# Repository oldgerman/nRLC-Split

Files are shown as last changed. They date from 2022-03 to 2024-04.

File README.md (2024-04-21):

## nRLC-Split

[nRLC音频头版](https://oldgerman.github.io/1eb159fd/) 的制造文件（Manufacturing documentation for nRLC-Split）

### 关于

你第一次接触到本套文件可能是压缩包，内容可能滞后于仓库，制作前请访问[仓库地址](https://github.com/oldgerman/nRLC-Split)检查更新

PCB、原理图、钢网、外壳文件后续可能会改动，以最新的日期时间为准！

The first time you come into contact with this set of files, it may be a compressed package, and the content may lag behind the warehouse. Please visit the [github](https://github.com/oldgerman/nRLC-Split) to check for updates before making

PCB, schematic, stencil, and shell files may be changed later, the latest date and time shall prevail!

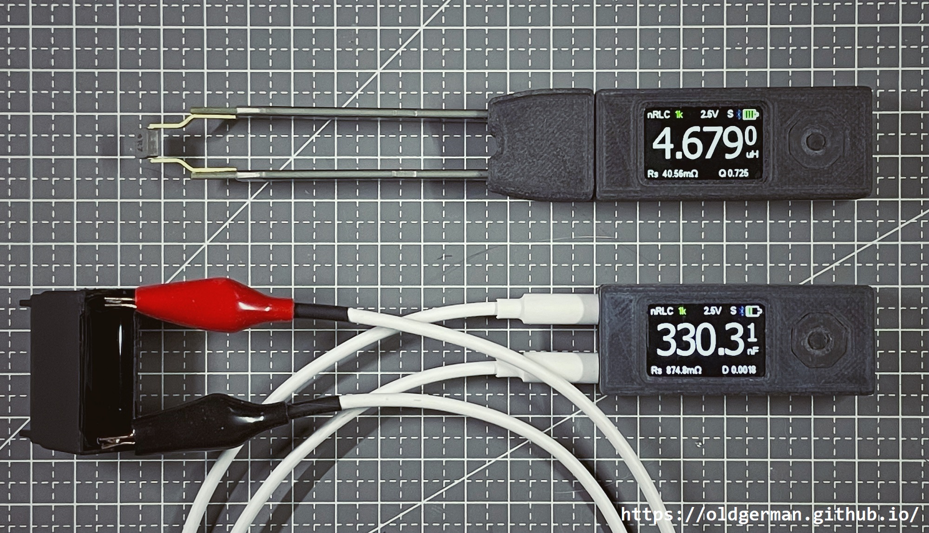
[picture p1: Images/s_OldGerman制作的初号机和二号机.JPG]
s_OldGerman制作的初号机和二号机


### 路径下各个文件夹的说明

```c
├─BOM                             // # PCB的物料清单，交互式BOM，使用浏览器打开
├─CAD                             // # 镊子触片CAD文件
├─Gerber                          // # 打板文件
│  ├─nRLC-Split                   // ## 【4层，板厚1.0mm】音频头版PCB
│  └─nRLC-Tweezers                // ## 【4层，板厚1.6mm】镊子PCB
├─Images                          // # 图片
├─Manual                          // # GFX网盘手册，添加了中文机器翻译
├─SCH                             // # 原理图
└─STL                             // # 3D打印模型
```

### 注意事项

PCB、原理图、钢网、外壳文件后续可能会改动，以最新的日期时间为准！

### 更新日志

| 日期 | 概述 | 制造文件变动 | 备注 |
| --- | --- | --- | --- |
| 2024-0504 之前 | 无 | 无 | 无 |
| 2024-0421 | 根据GFX网盘手册更新精确匹配的元件，在原理图中以粉色字体标出 | BOM、原理图  | 保留过去的BOM、原理图版本，但文件名添加了日期前缀 |

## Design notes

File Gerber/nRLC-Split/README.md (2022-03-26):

## PCB工艺 (PCB process)

PCB：4层板

厚：**1.0mm**

最小间隙：5mil

Gerber文件叠层顺序：GTL, G1, G2, GBL

PCB：4 layer 

Thickness：**1.0mm**

Minimum clearance：5mil

Gerber files stacking order: GTL, G1, G2, GBL

## 钢网 (SMT Stencil)

可以使用本路径下的 SMT_Stencil.GBP 文件给厂家制作10x10cm钢网，上下两张板的正反面都拼在这个文件内

You can use the SMT_Stencil.GBP file in this path to make a 10x10cm steel mesh for the manufacturer, and the front and back sides of the upper and lower boards are assembled in this file

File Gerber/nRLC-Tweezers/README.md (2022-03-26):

## PCB工艺 (PCB process)

PCB：4层板

厚：**1.6mm**

Gerber文件叠层顺序：GTL, G1, G2, GBL

PCB：4 layer 

Thickness：**1.6mm**

Gerber files stacking order: GTL, G1, G2, GBL

## 2021/03/24 文件修改 (Modify the files)

请使用PCB-Tweezers_0324_ZT.zip文件，修改部分：将3.5音频连接器悬空的第4引脚进行接地

这个修改不是致命缺陷，之前打过PCB-Tweezers_0301_ZT.zip文件的朋友不会产生本质的问题，具体区别如下：

- PCB-Tweezers_0301_ZT.zip文件：两条测试信号线在3.5音频连接器内部被第3脚包地

- PCB-Tweezers_0324_ZT.zip文件：两条测试信号线在3.5音频连接器内部被第3脚和第4脚包了两次地

Please use the PCB-Tweezers_0324_ZT.zip file, modified part: connect the 4th pin of the 3.5 audio connector to ground.

This modification is not a fatal flaw. Friends who have previously typed the PCB-Tweezers_0301_ZT.zip file will not have essential problems. The specific differences are as follows:

- PCB-Tweezers_0301_ZT.zip file: The two test signal lines are grounded by pin 3 inside the 3.5 audio connector.

- PCB-Tweezers_0324_ZT.zip file: The two test signal lines are grounded twice by pins 3 and 4 inside the 3.5 audio connector.

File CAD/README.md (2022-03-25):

## 镊子接触头CAD文件

文件`Tweezers_tips.DWG`和`Tweezers_tips.DXF`用软件导入查看时，单位请选mm

注意：激光切割只切外轮廓，不要切割两条折弯线

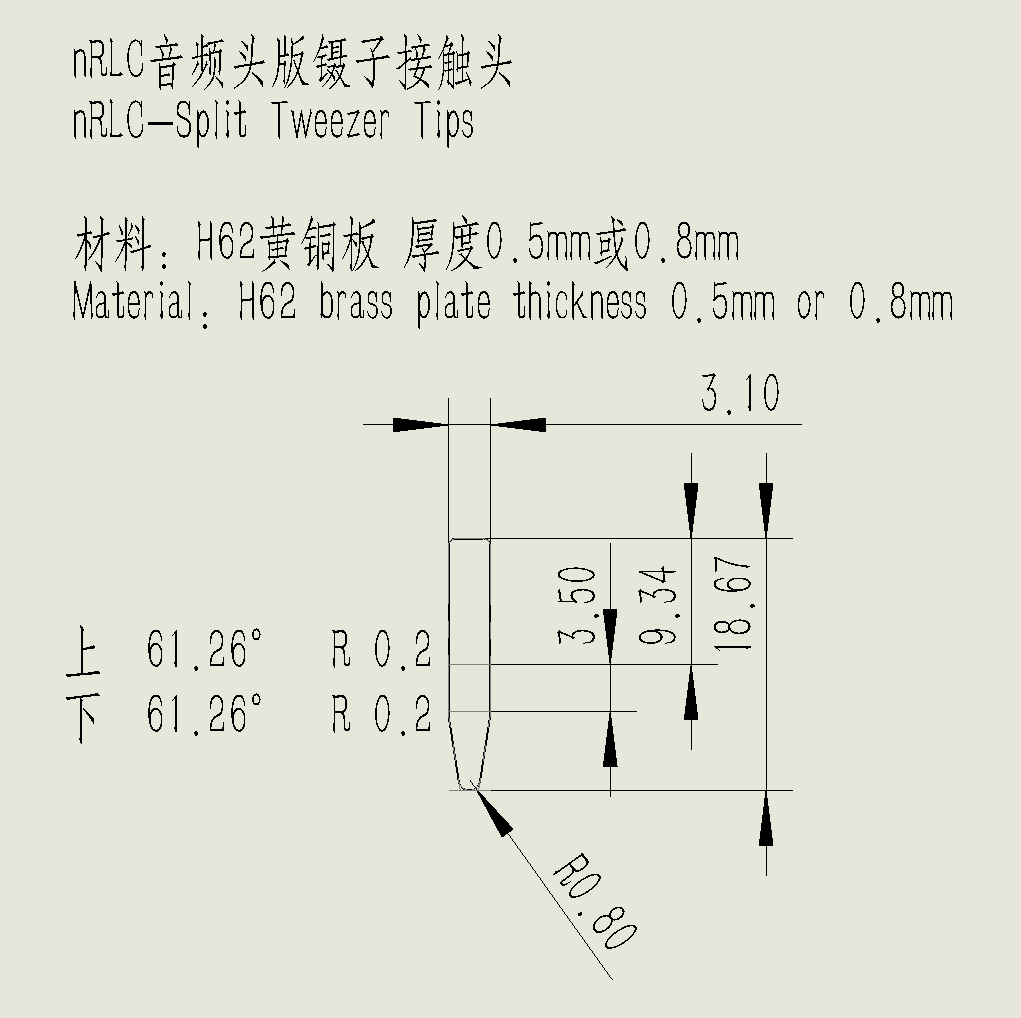
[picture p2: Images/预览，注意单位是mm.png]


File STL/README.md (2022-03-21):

## 外壳打印文件

###  一套外壳固定用的五金件

不锈钢内六角螺丝杯头 x5
	规格：M1.6x12 (螺纹/螺纹的长度)，[链接](https://item.taobao.com/item.htm?id=40272016203)

注塑热熔铜滚花螺母 x5
	规格：外2.5 M1.6 1.5高，[链接](https://item.taobao.com/item.htm?id=39063858665)

### 中心按钮

打印的中心按钮尺寸不一定精确，中心按钮装入周围按钮后，底部最好和周围按钮一样平，按下按键才不会误触，不平的话请用3mm圆锉刀修整侧壁

### 整机收纳壳

中心按钮预留高度较高，装入整机收纳壳需要打磨一定厚度

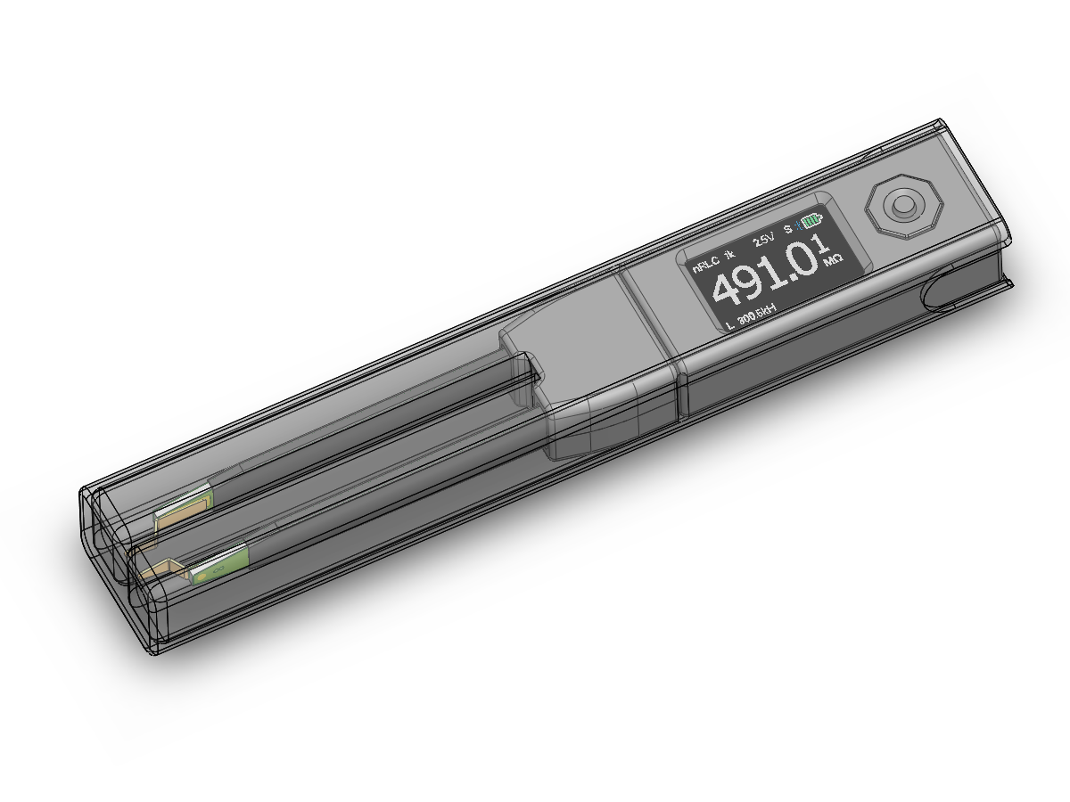
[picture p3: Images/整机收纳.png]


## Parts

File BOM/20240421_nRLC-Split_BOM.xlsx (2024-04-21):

Comment | Description | Designator | Footprint | LibRef | Quantity
Lipo_Battery_402030_180mAh |  | [NoValue], *1 | 402030锂电池180mAh(28x20x4mm) | Lipo_Battery | 2
ODG_LOGO |  | [NoValue], *2, *3, *4, *5, *6, *7, *8 | ODG_LOGO | ODG_LOGO | 8
BAT |  | BAT1 |  | BAT | 1
1uF | Capacitor | C1, C3, C5, C9, C10, C11, C13, C15, C16, C17, C19, C20, C23, C24, C26, C29, C31, C32, C33, C35, C36, C39, C41, C43, C48, C61, C63, C65, C67, C71, C73 | C0603 | CAP | 31
10uF | Capacitor | C2, C25, C38, C40, C42, C45, C47, C49, C53, C54, C55, C56, C59, C66, C68, C72 | C0603 | CAP | 16
47uF/6.3V | Capacitor | C4, C8, C12, C14, C21, C30, C37 | CAP_POL_3216 | CAP_Polar | 7
100pF | Capacitor | C6, C7 | C0603 | CAP | 2
100pF/1% | Capacitor | C18, C22, C27, C34 | C0603 | CAP | 4
N/I | Capacitor | C28, C46, C50, C52 | C0603 | CAP | 4
0.1uF | Capacitor | C44, C51, C60, C62, C64, C69, C70 | C0603 | CAP | 7
10pF | Capacitor | C57, C58 | C0603 | CAP | 2
1nF | Capacitor | C74 | C0603 | CAP | 1
SRV05-4MR6T1G | 钳位IC | D1 | MICROCHIP SOT-23-6 M6 | SRV05-4 | 1
USBLC6-2 | Very low capacitance ESD protection Features • 2 data-line protection • Protects VBUS • Very low capacitance: 3.5 pF max. • Very low leakage current: 150 nA max. • SOT-666 and SOT23-6L packages • RoHS compliant | D2 | MICROCHIP SOT-23-6 M6 | USBLC6-2 | 1
1N4148WT |  | D3 | SOD-523 | DIODE | 1
AD8605ARTZ | 精密、低噪声、CMOS、轨到轨输入/输出运算放大器 | DA1, DA5 | ANALOG SOT-23-5 RJ-5 | AD8605ARTZ | 2
AD8542ARMZ或AD8542ARUZ | 通用型CMOS双路轨到轨放大器 General-Purpose CMOS Dual Rail-to-Rail Amplifier | DA2 | TSSOP-8+MSOP-8 | AD8542 | 1
INA826AIDGKR或INA826SIDRCR | 具有轨至轨输出和关断的 INA826S 精密 200µA 电源电流，3V 至 36V 电源 仪表放大器 | DA4, DA6 | MSOP-8+PVSON-10 | INA826S | 2
10uH |  | L1, L2, L3, L4, L5, L6, L7, L10, L11, L12 | L0603 | FUSE | 10
10uH_0805 |  | L8 | L0805 | FUSE | 1
2.2uH |  | L9 | TAIYO YUDEN MAMK2520T1R0M | Inductor | 1
LED | LED | LED1 | LED 0603_1608 | LED | 1
12mm 陶瓷蜂鸣片 | Speaker | LS1 | 压电陶瓷蜂鸣片12MM | Speaker | 1
PJ320 |  | P1, P2, P11, P12 | PJ320A | PJ320 | 4
1.27mm_10P_母座 | 1.27mm 母座 10pins | P3, P4 | 1.27mm_Female_x10 | DS1065-01-1X10S8BV | 2
1.27mm_10P_排针 | 1.27mm 排针 10pins | P5, P6 | 1.27mm_male_x10 | ZL319-10P | 2
1.27mm_2P_母座 |  | P7, P8 | 1.27mm_Female_x2 | CONN_2P | 2
1.27mm_2P_排针 |  | P9, P10 | 1.27mm_male_x2 | CONN_2P | 2
P-MOS | P-MOS | Q1, Q3 | INFINEON SOT-23-3 | P-MOS | 2
N-MOS | N-MOS | Q2, Q4 | INFINEON SOT-23-3 | N-MOS | 2
15K | Resistor | R1, R8 | R0603 | RES | 2
1K | Resistor | R2, R13, R21, R22, R26, R37, R61 | R0603 | RES | 7
5.1K | Resistor | R3, R57, R58 | R0603 | RES | 3
10R | Resistor | R4, R11, R14, R20, R60 | R0603 | RES | 5
100K | Resistor | R5, R6, R36, R38, R41, R51, R52 | R0603 | RES | 7
10K | Resistor | R7, R34, R39, R40, R43, R44, R48 | R0603 | RES | 7
100R | Resistor | R9, R23, R33, R54 | R0603 | RES | 4
22R | Resistor | R10, R15, R25, R29 | R0603 | RES | 4
30K | Resistor | R12 | R0603 | RES | 1
1M/0.1% | Resistor | R16, R31 | R0603 | RES | 2
2K/0.1% | Resistor | R17, R18, R24, R32 | R0603 | RES | 4
1M | Resistor | R19, R28 | R0603 | RES | 2
100R/0.1% | Resistor | R27 | R0603 | RES | 1
10K/0.1% | Resistor | R30 | R0603 | RES | 1
40.2K | Resistor | R35 | R0603 | RES | 1
N/I | Resistor | R42, R45, R46 | R0603 | RES | 3
47K | Resistor | R47, R53, R55, R59 | R0603 | RES | 4
2M | Resistor | R49 | R0603 | RES | 1
205K | Resistor | R50 | R0603 | RES | 1
1.5K | Resistor | R56 | R0603 | RES | 1
RES-8P4R-100R | 贴片网络排阻 | RN1 | RESNET 1206-8 CONCAVE | RES-8P4R | 1
RES-8P4R_100R | 贴片网络排阻 | RN2, RN4 | RESNET 1206-8 CONCAVE | RES-8P4R | 2
RES-8P4R_22R | 贴片网络排阻 | RN3 | RESNET 1206-8 CONCAVE | RES-8P4R | 1
KLS7-MT-08 | KLS五向开关10*10*1.5mm 兼容松下EVQQ3KA15 TT5 | SW1 | KLS7-MT-08 | KLS7-MT-08 | 1
PGA113AIDGST |  | U1, U2 | TI MSOP-10 DGS | PGA113 | 2
SN74LVC1G3157DCKR | 5V、2:1 (SPDT)、单通道通用模拟开关 5-V, 2:1 (SPDT), 1-channel general-purpose analog switch | U3, U4 | DIODES SOT-363 | SN74LVC1G3157DCKR | 2
MCP73831T或LTC4054或TP4054 |  | U5 | MICROCHIP SOT-23-5 OT | MCP73831T | 1
MCP1700T-3302E/TT | 低压差线性稳压芯片 | U6 | MICROCHIP SOT-23-3 NB | MCP1700T-3302E/TT | 1
ADP150AUJZ-3.3-R7或LDK 120M33R或LP5907MFX | 超低噪声线性稳压芯片 | U7 | ANALOG TSOT-23-5 UJ-5 | ADP150AUJZ-3.3-R7 | 1
STM32F303CCT6或STM32F303CBT6 | 带DSP和FPU的主流混合信号ARM Cortex-M4 MCU，具有128 KB Flash、72 MHz CPU、MPU、CCM、5 MSPS 12位ADC、PGA和比较器 | U8 | ST LQFP-48 7x7MM | STM32F303CBT6 | 1
CCR2640R2F | CC2640R2F 无线蓝牙串口模块 | U9 | 信驰达_RF-BM-4044B5 | 信驰达_RF-BM-4044B5 | 1
SPX3819M5-L-5-0/TR或TPS76350DBVR或SPX5205M5-L-5-0/TR | 超低噪声线性稳压芯片 | U10 | ANALOG TSOT-23-5 UJ-5 | ADP150AUJZ-3.3-R7 | 1
TPS63000 | Buck-Boost Converter 具有 1.8A 电流开关并采用 3x3 QFN 封装的高效率降压/升压转换器 | U11 | TI PVSON-10 3x3MM DRC | TPS63000 | 1
74HC1G32GV.125或SN74AHC1G32DBVR | IC GATE OR | U12 | TI SOT-23-5 DBV | SN74AHC1G32DBVR | 1
IPS-LCD-1.14inch | IPS-LCD-1.14寸裸屏spi接口 | U13 | TFT_1.14IN_240X135_WRAPUNDER | IPS-LCD-1.14inch | 1
BMI160 | IMU combining accelerometer and gyroscope. Package dimensions 2.5x3.0x0.8mm³ The small, low power BMI160 is a low noise 16-bit IMU designed for mobile applications such as AR or indoor navigation, providing highly accurate sensor data and real-time sensor data. The low current consumption of BMI160 enables always-on applications in battery-driven devices. This sensor features a configurable on-chip interrupt engine which provides motion-based gesture recognition and context awareness as always-on background functions. The BMI160 is compatible with the Qeexo FingerSense application. | U14 | BOSCH LGA-14 2.5x3 - large | BMI160 | 1
CCR2640R2F | CC2640R2F 无线蓝牙串口模块 | U15 | 信驰达_RF-BM-4044B4 | 信驰达_RF-BM-4044B5 | 1
Type-C_16P插脚（需要按照教程魔改） |  | USB1 | Type-C-TOP-前插后贴 | USB-Type-C-24P | 1
BAV99W | Dual Series Switching Diodes | VD1 | DIODES SOT-323-3 | BAV99W | 1
BAT54CW | 贴片肖特基二极管 | VD2, VD3 | DIODES SOT-323-3 | BAT54CW | 2
12MHz/10pF | 4脚无源晶振 | X1 | EPSON TSX-3225 | XTAL-4P | 1

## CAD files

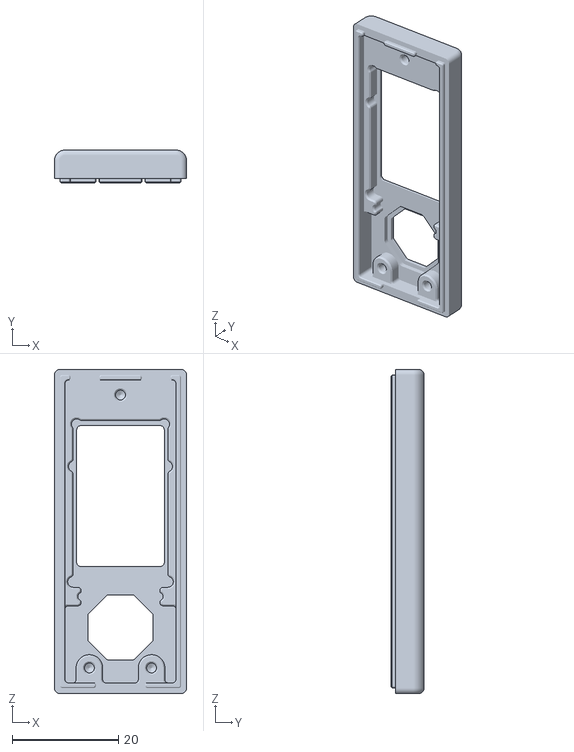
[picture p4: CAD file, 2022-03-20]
STL/主体外壳_上壳(main_body_shell_top).STL
24.8 x 6.20 x 60.9

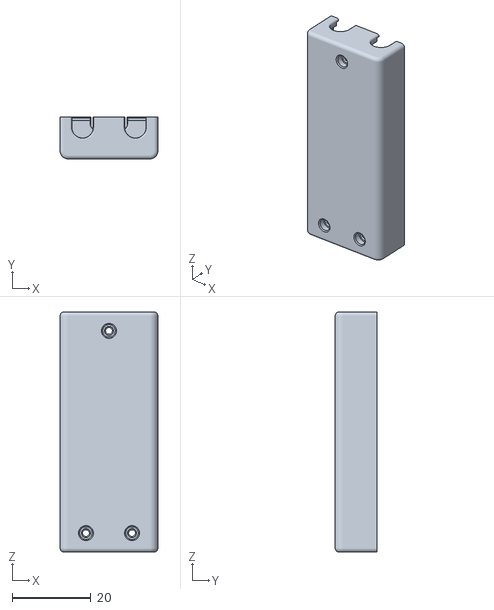
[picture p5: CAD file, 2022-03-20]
STL/主体外壳_下壳(main_body_shell_bottom).STL
24.8 x 10.6 x 60.9

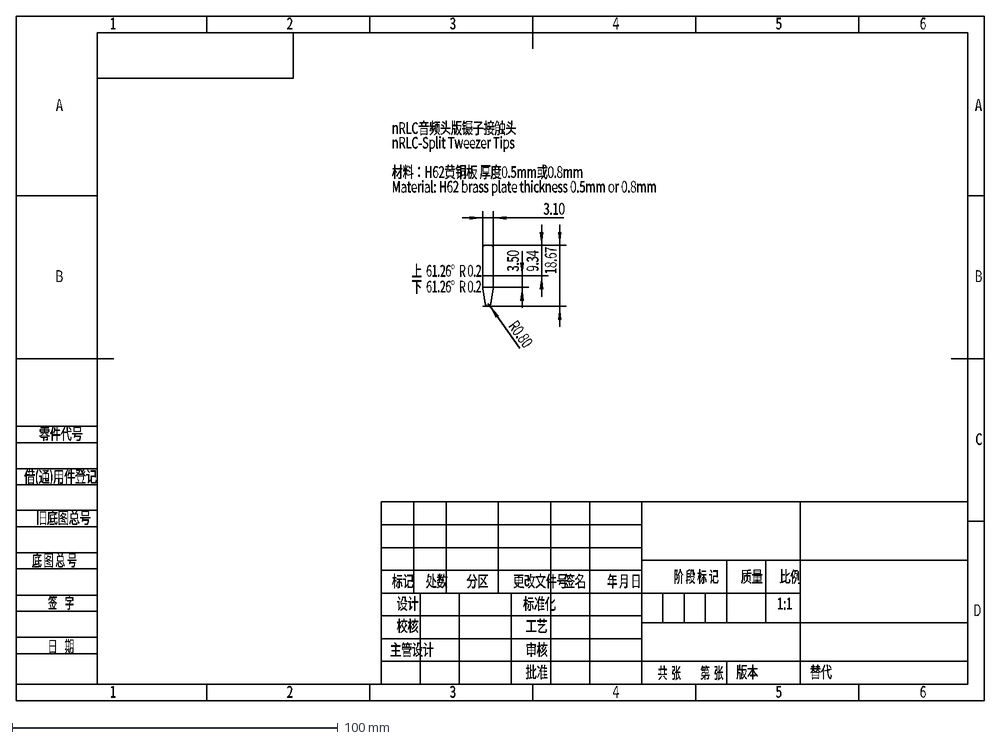
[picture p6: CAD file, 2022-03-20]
CAD/Tweezers_tips.DXF
nRLC音频头版镊子接触头
nRLC-Split Tweezer Tips
材料：H62黄铜板 厚度0.5mm或0.8mm
Material: H62 brass plate thickness 0.5mm or 0.8mm
替代
版本
审核
工艺
比例
质量
第 张
共 张
阶 段 标 记
批准
标准化
主管设计
年 月 日
签名
更改文件号
分区
处数
标记
设计
校核
零件代号
借(通)用件登记
旧底图总号
底 图 总 号
日 期
1:1
1
B
A
D
C
签 字
2
5
4
3
6
3.10
18.67
R0.80
9.34
3.50
上 61.26° R 0.2
下 61.26° R 0.2

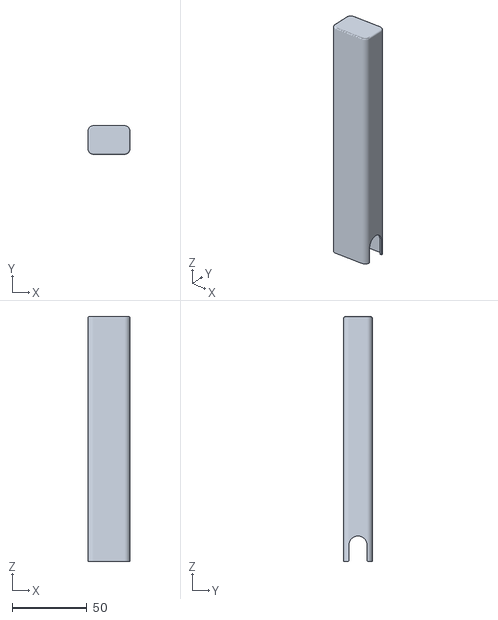
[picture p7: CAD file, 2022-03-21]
STL/整机收纳壳(machine storage case).STL
28.0 x 19.2 x 163.7

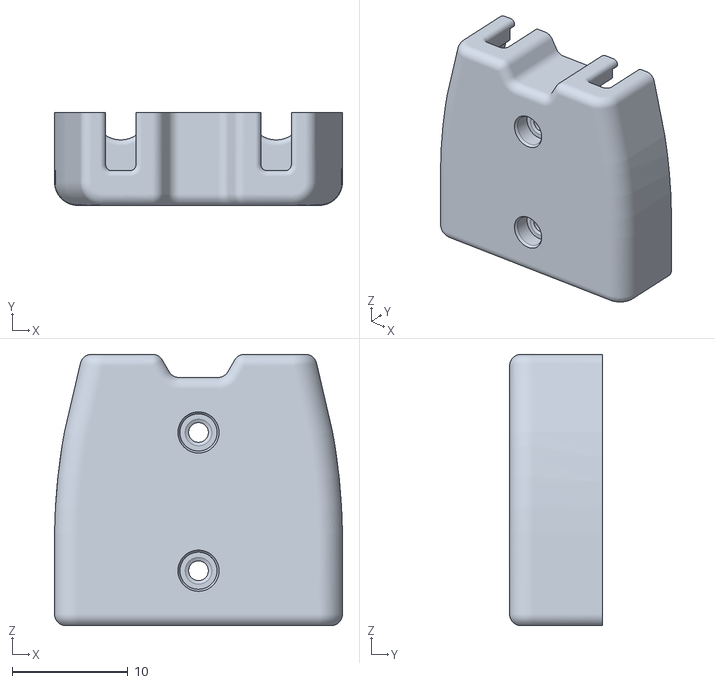
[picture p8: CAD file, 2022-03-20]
STL/镊子外壳-下壳(tweezers_case_bottom).STL
24.8 x 8.00 x 23.4

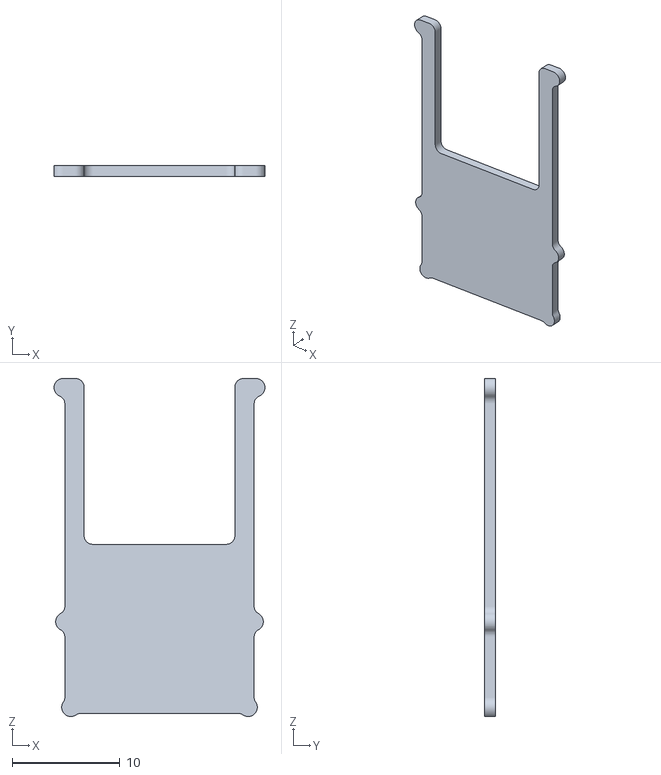
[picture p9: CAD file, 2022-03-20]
STL/屏幕垫片(display_gasket).STL
19.6 x 1.00 x 31.3

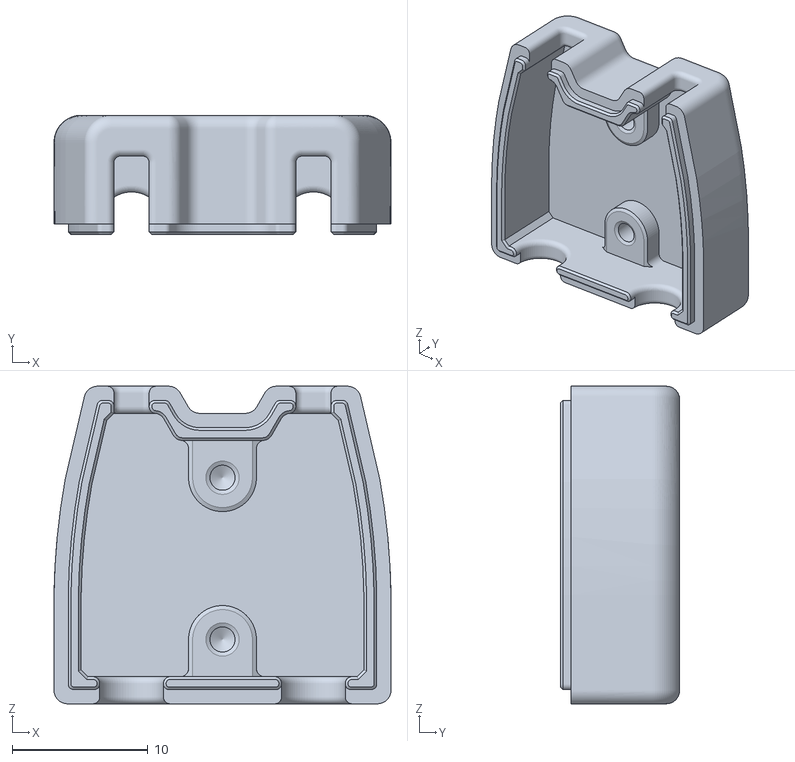
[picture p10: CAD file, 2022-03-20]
STL/镊子外壳-上壳(tweezers_case_top).STL
24.8 x 8.80 x 23.4

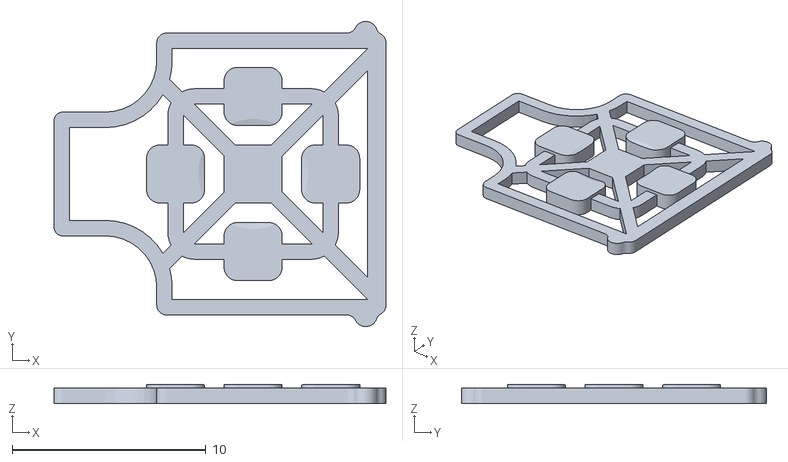
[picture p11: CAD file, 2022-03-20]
STL/按钮垫片(button_gasket)_0.8mm.STL
17.1 x 15.7 x 1.00

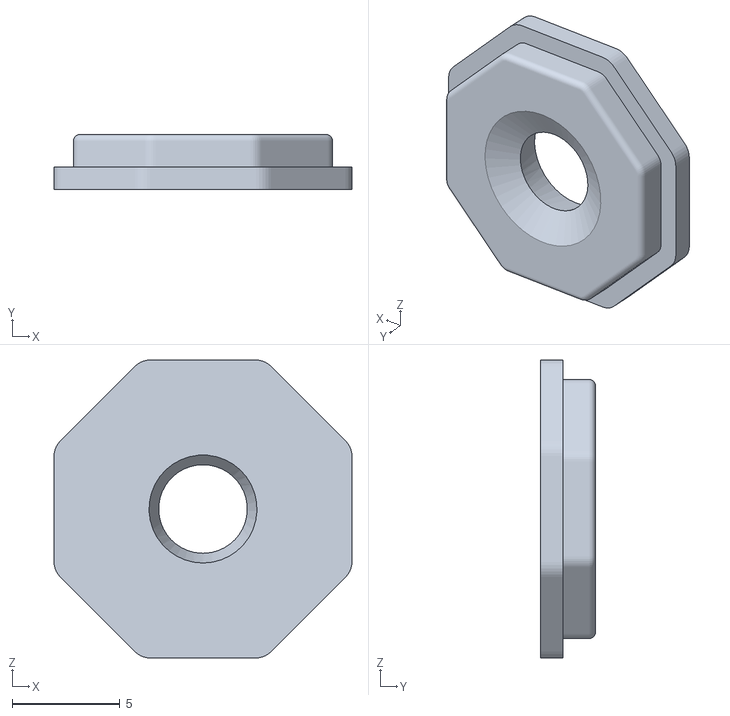
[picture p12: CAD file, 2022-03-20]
STL/周围按钮(surround_button).STL
13.8 x 2.55 x 13.8

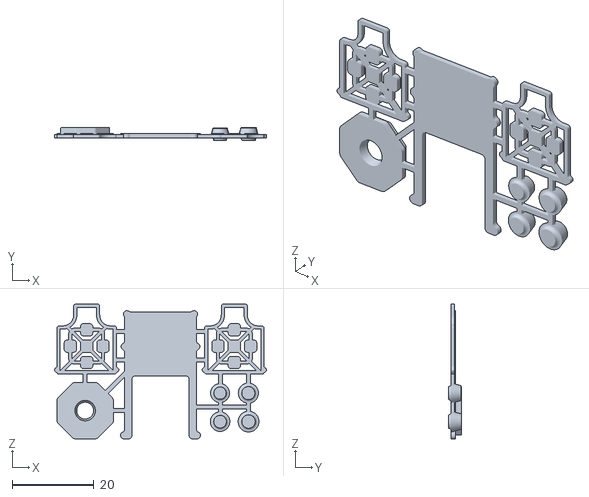
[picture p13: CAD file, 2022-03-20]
STL/链接零件(link_parts).STL
51.8 x 3.26 x 32.9

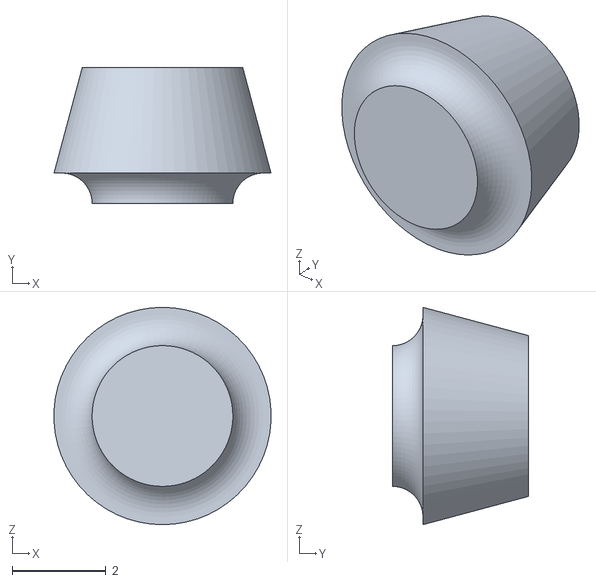
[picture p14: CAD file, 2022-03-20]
STL/中心按钮(center_button).STL
4.63 x 2.90 x 4.63

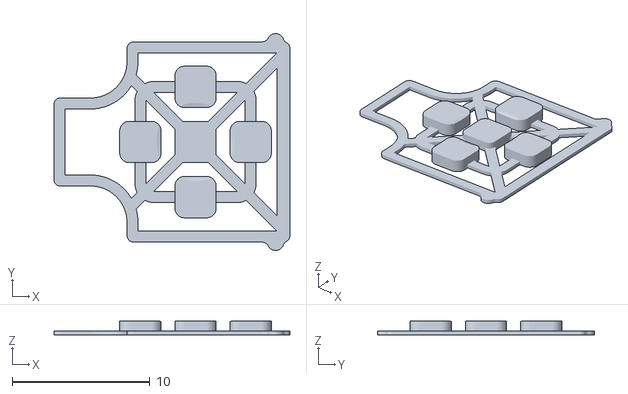
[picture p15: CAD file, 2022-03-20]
STL/按钮垫片(button_gasket)_0.3mm.STL
17.1 x 15.7 x 1.00

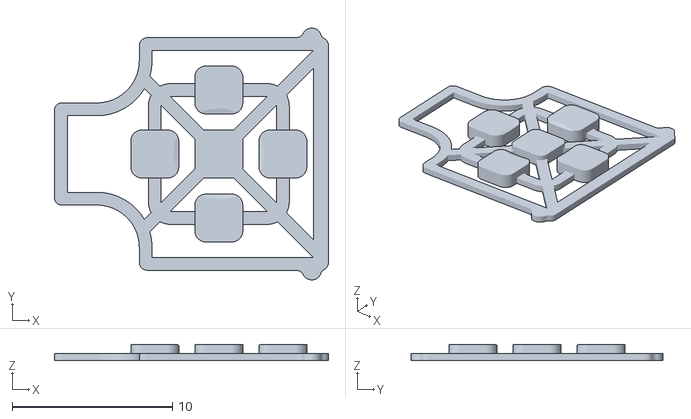
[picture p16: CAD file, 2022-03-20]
STL/按钮垫片(button_gasket)_0.45mm.STL
17.1 x 15.7 x 1.00

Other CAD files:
CAD/Tweezers_tips.DWG

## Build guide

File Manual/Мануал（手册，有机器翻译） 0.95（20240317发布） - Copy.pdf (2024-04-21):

Особенности схемотехники, подбор элементов.

ОУ недопустимо покупать у непрверенных поставщиков в т.ч у китайцев. В условиях дефицита (02.2022) на INA826 контрафактнеМС могут реализовываться и уважаемыми магазинами. МК брать у китайцев нежелательно, хотя и есть положительные отзывы по работоспособности. На качество работы прибора напрямую влияют встроенные АЦП которые в китайских МК могут быть низкого качества.
В схеме имеются элементы, которые должны быть прецизионные, либо специально подобранные. Качество подбора напрямую влияет на точность измерения.
К таким элементам относятся:
- Токовые шунты R1, R2 должны быть прецизионные резисторы с точностью 0,1%. Должны строго подбираться пары элементов в каналах напряжения и тока , абсолютный номинал не столько критичен, важно абсолютное равенство значений в паре. Отклонение в значениях в паре приведет к повышению погрешностей. Необязательно брать 0,1% резисторі, можно взять в избытке 1-5% и отсортировать равные.
R13= R15
R18=R20
R26=R27
C16=C18
Конденсаторы влияют тем больше, чем выше рабочая частота, низкокачественніе дополнительно вносят искажения в сигнал и снижают точность, должны устанавливаться обязательно NP0, подобранные в пары:
С16=С18,
С24=С25.
Данные конденсаторы можно не устанавливать до полного монтажа и настройки прибора, а отсортировать самим же прибором и установить после полного запуска.

Первичная оценка работоспособности. Проведение доработок. Собранный из качественных и подобранных элементов прибор в настройке не нуждается. Даже без калибровок должен измерять с погрешностью не хуже 0.5% в центре диапазона 100 Ом- 100К. Если это не так, следует искать причину, прежде всего в аналоговой части. Не пытайтесь калибровать прибор с кривоработающей аналоговой частью, необходимо найти и устранить причину,
Для поиска неисправностей имеются ряд встроенных инструментов:
- Инженерный экран
- Осцилографический экран
- Отключение ДАК в меню- позволяет отключить тестовый сигнал и убедиться в том, что в каждой контрольной точке имеется допустимое значение REF, отсутствует генерация/ возбуд и т.д

- Ручная установка РУИ, позволяет в ручном режиме проверить масштабируемость КУ программируемого усилителя, работу каждого шунта в отдельности и т .д

### Второй экран

(инженерный), переключается нажатием кнопки «Влево». Отображает всю доступную информацию измерения и расчетов.

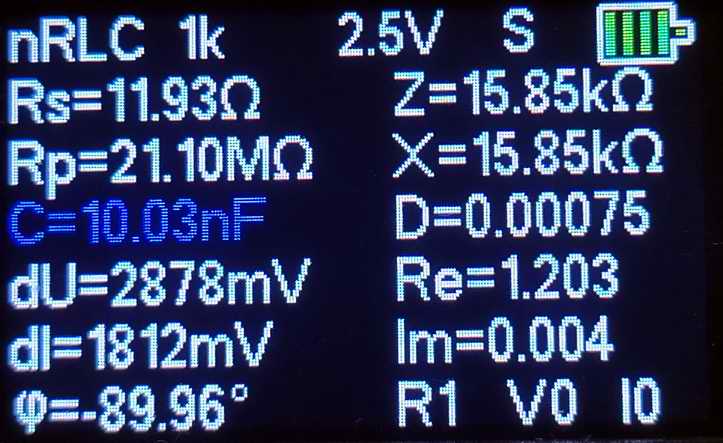
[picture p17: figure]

Rs- сопротивление последовательное, Rp- сопротивление параллельное, C- емкость,
dU- амплитуда АЦП напряжения,
dI- амплитуда АЦП тока
Фи -89.96* - угол фазы каналов напряжения и тока, отрицательный для конденсатора, положительный для индуктивности, близкий к нулю для резистора.
Z - полное (комплексное) сопротивление
X – реактивное сопротивление
D – в данном случае тангенс потерь. Может быть добротность
Re% - СКО активной части сопротивления (среднеквадратичное отклонение) между выборками в цикле измерения, является индикатором точности измерения, однако % СКО не является % погрешности
Im%- СКО реактивной части.
R1V0I0- номер подключенного шунта и КУ ПГА напряжения и тока
R1 - значение подключенного шунта R0-100R , R1-10K,
V0 - Значение КУ PGA канала напряжения V0- КУ=1, V1- КУ=2, V5- КУ=50
I0 - Значение КУ PGA канала тока I0- КУ=1
При разомкнутых щупах обычно отображается большое сопротивление и большая индуктивность, либо большое сопротивление и сверхмалая емкость. При замкнутых -низкое сопротивление и малая индуктивность/ большая емкость. При выходе за

максимальные пределы, когда расчетное значение выходит за рациональные пределы в режиме OPEN значения номиналов могут не отображаться вовсе, не отображаются на основном экране так же отрицательные значения сопротивления, что рассматривается как ошибка измерения/ калибровки и т.д.
На втором экране отображаются все значения в т.ч некорректные или выходящие за пределы.

## Осциллографический режим

Режим вызывается нажатием кнопки «Вправо». Необходим прежде всего как диагностический инструмент. Отображает амплитуду, форму и разность фаз каналов Напряжения и Тока АЦП МК, 10 и 16 пин МК.

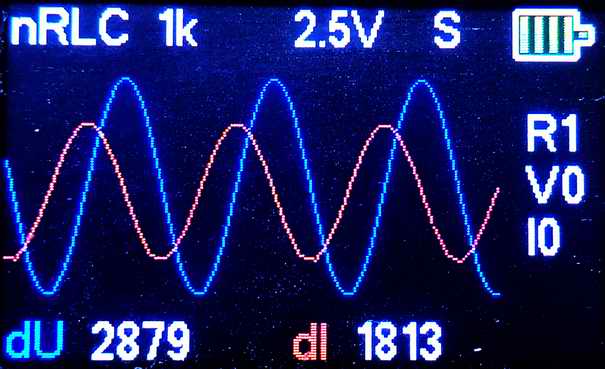
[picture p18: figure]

Синий луч- канал напряжения, красный- тока, под лучами отображается числовое значение амплитуд в мВ р-р. Справа- режим RUI- - номер подключенного шунта и КУ ПГА напряжения и тока.
По форме сигналов можно судить о корректности работы прибора. Форма сигналов в установившемся режиме должна быть синусоидальной, без клиппинга «срезания» верхушек, с центральным расположением лучей, без существенных смещений. В момент переключения режимов, например при подключении или отключении детали происходит подбор оптимальных режимов шунтов, КУ усилителей, в этот момент наблюдаются существенные изменения амплитуд, клиппинг.
На скриншоте результат с подключенным измеряемым элементом- конденсатор 10 нФ. Элемент формирует смещение фазы почти -90 градуов, что проявляется в смещени лучей друг относительно друга.
При измерении резисторов фаза будет почти нулевой. Смещение фазы указывает на наличие реактивного сопротивления емкостной или индуктивной природы.
При измерении сверхмалых сопротивлений (Short) канал тока будет иметь максимальную амплитуду, канал напряжения минимальную. При измерении сверхбольших сопротивлений канал тока будет иметь малую амплитуду, канал напряжения-максимальную. На каналах с малой амплитудой может наблюдаться наличие шума/ наводок, особенно в условиях высокого ЭМ фона или при измерении массивных деталей, на которых могут наводиться помехи.
Программа для ПК имеет окно с отображением осцилограмм напряжения и тока, работает аналогично.

Контрольные значения

Приводятся скриншоты с параметрами работы авторского экземпляра прибора, тестовый сигнал 2,5В 1,кГц, прибор не калиброван.
Если ваши значения сильно отличаются – что- то пошло не так.

Опен

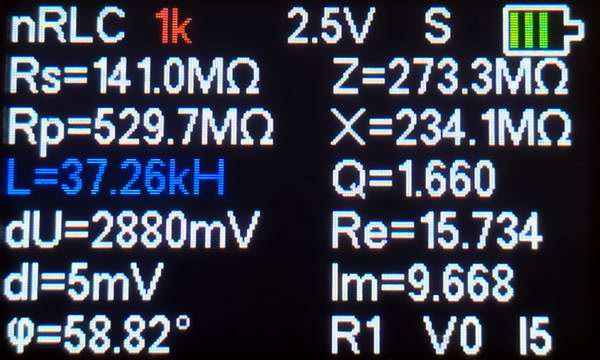
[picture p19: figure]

Rs должно быть максимально большим, его значение зависит от отношения величины амплитуды напряжения и тока с учетом КУ ПГА.
В опене амплитуда dU максимальна,dI минимальна,
Важен параметр Re, чем меньше, тем лучше- меньше помех, стабильней результат. Большое значение может свидетельствовать об вісоких наводках на входную часть, вісоких пульсациях по цепям питания, наличии клиппинга.

Шорт

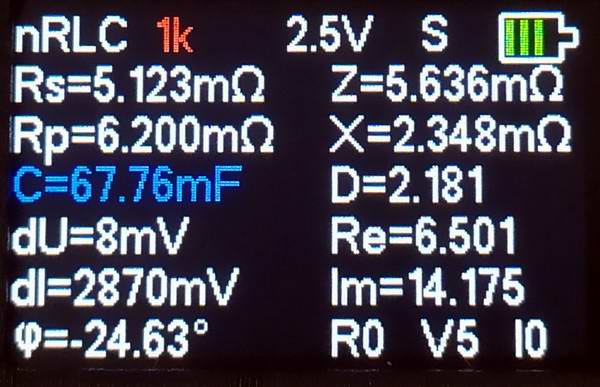
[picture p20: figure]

Чем ниже Rs до калибровки, тем качественней щупы
В шорте dI – ток максимальный, dU- напряжение на щупах минимально.
Re Im особо нет смысла сравнивать, поскольку они сильно зависят от сопротивления контакта, с плохим контактом получаются более высокие амплитуды на АЦП, стабильнее замер, лучше Re Im , но это эквивалентно измерению сопротивления 50 мОм вместо 5 мОм.

100R

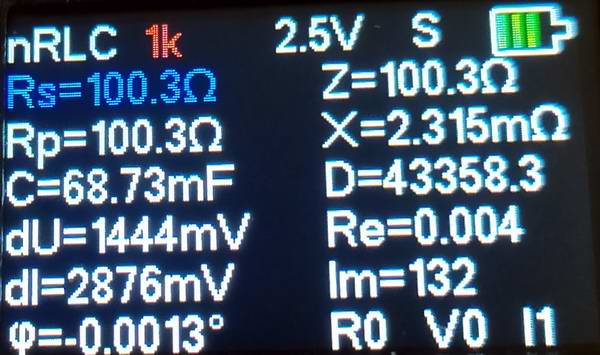
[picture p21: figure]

Без калибровки для 100 Ом (0,1%) погрешность получается около 0,3% без калибровки . Угол Фи для «хороших» резисторов должен быть близок к нулю.
Re = 0,004. Im нет смісла сравнивать из-за чрезмерно большого отношения активного и реактивного сопротивления – почти 5 порядков.
100K

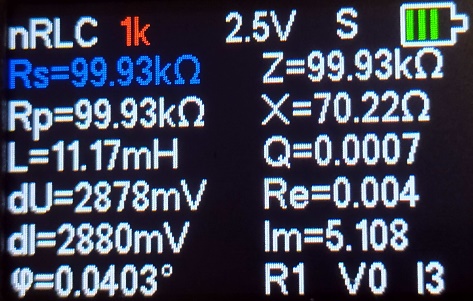
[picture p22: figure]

100К 0,1% резистор, Rs 99, 93K условно 0,1% погрешности.
Угол Фи по-прежнему стремится к нулю.
Re 0, 004%, Im особо не имеет значения, не репрезентативній в данном случае параметр.

10нФ

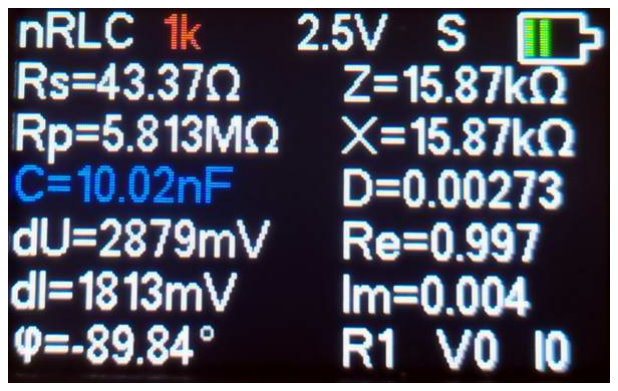
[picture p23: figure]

10нф 250В 0,5% к71-7В. качественный конденсатор для сравнения.
Емкость 10,02 нФ.
Угол фи для идеального конденсатора равен -90 градусам. Чем лучше конденсатор, тем ближе к єтому значению. Чем хуже, тем ближе угол к нулю. Чем лучше качество конденсатора, тем сложнее измерить его второй и 3-й параметры, тем точнее должна быть калибровка.
Параметры Фи, Rs, D взаимосвязаны между собой и без калибровки измеряются с высокой погрешностью. В отличии от основного параметра С.
Для данного конденсатора Тангенс угла диєлектрических потерь указан не более 0,001, у нас D=0,0027

Im= 0,004%

Пользуясь сравнением Re для резисторов и Im для реактивностей- конденсаторов и дросселей можно оценивать качество работы прибора, а так же результат проведения различных доработок- измерили серию контрольных элементов, зафиксировали значения Re,Im, произвели доработку, сравнили Re,Im для тех же элементов.

Управление.
Управление прибором осуществляется 5-ю кнопками джойстика, при этом используются так же нажатие 2-х кнопок одновременно, а так же удержания.
Кнопка ОК:
- включает прибор, коротким или длинным нажатием,
- длительное нажатие выключает прибор,
- короткое нажатие во включенном состоянии вызывает основное Меню настроек. В настройках короткое нажатие работает как подтверждение выбора,
- Нажатие Вверх+ Ок с удержанием переводит прибор в режим программирования через DFU режим,
- Нажатие Вниз+ ОК перезагружает МК (Reset),
Кнопка Вверх:
- Нажатие Вверх+ Ок с удержанием переводит прибор в режим программирования через DFU режим,
- Во включенном состоянии повышает тестовую частоту на один шаг (на полной прошивке),
- В меню листает пункты вверх или добавляет +1 пункт в числовых значениях калибровки,
- При удержании Вверх в меню происходит быстрый выход минуя все дерево настроек в рабочий режим,
- При удержании Вверх в рабочем режиме включается- выключается Блютуз.
Кнопка Вниз:
- Нажатие Вниз+ ОК перезагружает МК (Reset),
- Во включенном состоянии понижает тестовую частоту на один шаг (на полной прошивке),
- В меню листает пункты вверх или убавляет -1 пункт в числовых значениях калибровки,
- При удержании Вниз в меню происходит быстрый выход минуя все дерево настроек в рабочий режим.
Кнопка Влево:

- переключает Основной режим- Инженерный режим
- длительное удержание переключает схему замещения измеряемого элемента Ser- Par (последовательную- параллельную).
Кнопка Вправо:
- переключает Основной режим- Режим осциллограмм,
- длительное удержание переключает амплитуду тестового сигнала 2,5- 0,25В р-р.

Калибровка прибора.

Необходима для более точного измерения на различных пределах. Возможна эксплуатация прибора без калибровки, с частичной или полной калибровкой.
Точность работы без калибровки зависит от точности установленных шунтов, а так же выбранной частоты, номинала детали, чем выше частота, тем больше влияют паразитные параметры схемы. Так же чем ближе номинал к низкоомному или высокоомному краю измерительного диапазона, тем выше необходимость калибровки.
В случае перепрошивки устройства через ST-Link желательна прошивка без полного стирания, в таком случае не затирается калибровка и не нужно проводить ее повторно, Однако бывают редкие случаи когда необходимо программировать с полным стиранием иначе программирование проходит некорректно.
Калибровка проводится на каждой частоте отдельно. Чем тщательнее проводится калибровка, тем точнее измерение. Точная калибровка необходима для разделения 2-х параметров измеряемого радиоэлемента с различными порядками сопротивлений. Например отделения очень маленькой индуктивности резистора 20 нГн от активного сопротивления 100 Ом. Либо измерение последовательного сопротивления конденсатора, либо же измерение тангенса диэлектрических потерь конденсатора.
Следует учитывать, что сам факт сведения щупов приводит к изменению емкости, даже резисторы в разных корпусах будут дать минимальную, но определяемую погрешность, особенно если это высокоомные значения при достаточно высокой частоте измерения. Для калибровки желательно использовать СМД резисторы типоразмера от 0805- 1206, в идеальном случае прецезионные 0,1% (как правило реальная погрешность существенно ниже заявленной), в случае отсутствия можно применять с любым допуском при условии измерения реального значения (например 1002,1 Ом тогда выбираем пункт «Установить R» выбираем значение ) сопротивления и внесения его в соответствующий пункт перед калибровкой.
Помимо основного параметра все элементы имеют дополнительные паразитные параметры, которые могут оказывать влияние,
Для калибровки Short лучше не сводить кончики вместе, а зажимать специально откушенную ножку, не склонную к значительному окислению какой-нибудь радиодетали. Практика показала, что такой метод точнее, чем калибровка при простом сведении.

Калибровка Open – Short наиболее практична, поскольку компенсирует неточность в самых критичных областях на краях диапазона, в середине диапазона, кроме случаев измерения на ВЧ, и так все ОК. В большинстве сценариев использования этого достаточно.
Может проводиться и частичная калибровка, например если нужно измерить низкоомные резисторы 10-100 мОм можно откалибровать часть диапазона Short- 1 Ом.
Полная калибровка Open – Short- Load. Выполняется по порядку указанному в меню. Для режима Short имеется возможность корректировки индуктивности- Пункт «Замкнутый set L». Этот пункт необходим для безупречной корректировки фазы и соответственно реактивной составляющей. Так в режиме шорт сигнал в канале напряжения имеет малую амплитуду из-за чего возникают ошибки калибровки фазы/ реактивной составляющей. Выглядит это примерно так –после калибровки и повторного смыкания щупов имеем показания 1,2 мОм 12 нГн вместо 1,2 мОм и 0-1 нГн. Т.е индуктивность при калибровке не компенсируется, внося в меню калибровки некоторое значение коррекции (например -10нГн) мы можем получить калибровку когда будет нулевая индуктивность. Функция применима для измерения ВЧ катушек индуктивности до 100нГн в прочих случаях особо нет смысла ею пользоваться.
Корректировка значений происходит следующим образом:
Пример:
После проведения калибровки Open- Short 10кГц, сохраняем, смотрим результат калибровки на Short
Rs= 0,7 mR
L= 0,5nH
в меню калибровки выбираем например пункт «Замкнутый set L» кнопками «Вверх-Вниз » добавляем или убираем верхний разряд корректируемой величины, например было 0,000 nH, выбрали 5,000 nH, нажали «Ок», при этом поле выбора сместилось на второй разряд, таким образом выбирая больше- меньше можно установить поразрядно любое значение, после последнего разряда нажатие «Ок» выводит из меню настройки коррекции. Таким образом корректировочная индуктивность выбрана 5 nH
Если теперь закоротить щупы, то увидим

Подобным же образом реализованы корректировки паразитных емкости (Cr) и индуктивности (CL) калибровочных резисторов. Выбираем соответствующие пункты «Установить С», «Установить L»,

Следует иметь ввиду, что коррекция работает и после самой калибровки, т.е можно произвести калибровку и затем повторно зайти в калибровку и несколькими итерациями подобрать нужную коррекцию. Либо произвести точную подгонку позже.

Корректировку целесообразно проводить для 1 Ом калибровочного резистора по индуктивности, или для высокоомных резисторов по емкости, особенно с ростом частоты. В середине диапазона или на достаточно низких частотах паразитные параметры не несут существенного вклада в погрешности.
Далее приведу цитату из руководства по калибровке RLC-2 прекрасно иллюстрирующей и калибровку данного прибора. Описанный далее метод не рекомендуется для всех из-за чрезмерной трудоемкости, нужен только «для ловли блох», но ознакомление с ним помогает понять суть процессов:
«Было выявлено экспериментально, что не точно введенная емкость резистора (Cstd) при LOAD калибровке сказывается на точность измерения тангенса угла диэлектрических потерь конденсаторов, измеренных на этом же диапазоне. И особенно на тангенс угла потерь высокодобротных конденсаторов. Так же Rs или Rp конденсатора может измеряться не правильно, сдвигаться в сторону увеличения или уменьшения, и даже получиться отрицательным …
чем выше диапазон, тем большее влияние неправильно заданной емкости Cstd резистора на тангенс, Rs или Rp измеряемого конденсатора. Фактически, задавая емкость резистора при LOAD калибровке, мы задаем фазовый угол для диапазона. Если угол зададим не правильный для резистора, то и при измерении конденсатора этот угол будет не правильным. Небольшая не точность угла заметно не скажется на измерении R и тангенса низкодобротных конденсаторов, но зато скажется заметно на высокодобротных. Авторы рекомендуют калибровать прибор по СМД резисторам с известной емкостью, порядка 0,08 пФ, задавая в меню Cstd резистора 0,08 пФ. Но дело в том, что выполнив OPEN калибровку с раздвинутыми щупами, а потом сдвинув щупы до расстояния между выводами СМД резистора, мы получим значительную прибавку емкости – до нескольких десятых пикофарад, а это означает, что введенная Cstd резистора 0,08 пФ будет далека от реальной, и LOAD калибровка диапазона выполнится не точно, то есть фазовый угол для диапазона будет выставлен не правильно, и это скажется не только на измерении емкости резисторов на этом диапазоне, но и на тангенсе и Rs, Rp конденсаторов. Чтобы максимально точно скорректировать фазовый угол , надо подбирать в меню Cstd резистора для LOAD калибровки, проверяя потом правильность калибровки по тангенсу высокодобротного конденсатора на этом же диапазоне.
LOAD калибровку со щупами типа "крокодил" я рекомендую делать по выводным резисторам. Из-за их большего расстояния между выводами, прибавка емкости от сближения щупов будет меньше. Хотя, можно калибровать и по CMD резисторам, но подобрать емкость резистора будет сложнее.
OPEN калибровку рекомендую делать с раздвижением щупов на какое-то максимальное расстояние… Это чтобы при повторной OPEN калибровке выдерживать то же расстояние, чтобы емкость между щупами не изменилась. Дело в том, что данные OPEN калибровки используются в формуле для коррекции результата измерения. И эти данные должны быть неизменными после выполнения OSL калибровки. Если же после правильно выполненной OSL калибровки повторить OPEN калибровку с другим расстоянием между щупами, то это скажется при измерениях и на тангенс угла потерь высокодобротных конденсаторов и на измеренную емкость резисторов на верхних диапазонах.
Теперь по самой методике OSL калибровки.

Перед калибровкой желательно исключить возможные источники помех,
OPEN калибровку выполняем с раздвижением щупов на сравнительно большое расстояние…
SHORT калибровка выполняется, как обычно. Зажимаем в щупы перемычку, максимально сдвигая щупы друг к другу. Перемычку надо использовать одну на случай повторной SHORT калибровки. Подойдет медный луженый провод диаметром 0,5-1 мм, можно использовать медный вывод резистора мощностью 0,5-1 Вт.
Кроме известного ряда прецизионных резисторов, надо еще заготовить ряд высокодобротных конденсаторов таких номиналов:
0,5 пФ (я соединял два последовательно по 1 пФ, тип КД);

### 10 пФ (два последовательно 22 пФ, или три последовательно 33 пФ, тип КМ или

пленочные полипропиленовые);
100 пФ (КМ, или пленочный полипропиленовый, или полистирольный);
1000 пФ (пленочный полипропиленовый или полистирольный):
0,01 мкФ (пленочный полипропиленовый или полистирольный);
0,1 мкФ (пленочный полипропиленовый или полистирольный).
Номиналы конденсаторов выбраны такие, чтобы они попадали приблизительно в середину диапазонов. Конденсаторы желательно подобрать по минимальному Rs (то же самое, что по минимальному тангенсу), это можно сделать даже на не точно откалиброванном измерителе RLC-2. Особенно это касается керамических конденсаторов, потому что они имеют больший разброс по тангенсу, по сравнению с пленочными полипропиленовыми или полистирольными. Но подбор конденсаторов по минимальным Rs и D не даст нам истинных значений этих параметров, надо их (истинные значения) где-то взять. И лучше было бы измерить тангенс ряда конденсаторов на профессиональном измерителе и потом подстроить до такого же значение свой. У меня нет такой возможности, поэтому я купил конденсаторы WIMA FKP2, надеясь, что тангенс у них мало зависит от частоты и от номиналов, вот выписал из даташита:
для C ≤ 1000 pF, tgδ ≤ 0,0003 (на частотах 1 и 10 кГц);
для C больше 1000 pF, tgδ ≤ 0,0004 (на частотах 1 и 10 кГц).

После калибровки своего измерителя по описанной здесь методике я сравнил тангенс купленных 4,7 нФ и 10 нФ WIMA FKP2 (полипропиленовыми) с К71-7 (полистирольными), намерил такое:
WIMA FKP2: tgδ(1 кГц) 0,0005...0,0006;
К71-7: tgδ(1 кГц) = 0,0003...0,0004.
Удивительно, но советские К71-7 оказались лучше по тангенсу, не смотря на то, что в технических характеристиках норма тангенса выше, чем у WIMA FKP2:
К71-7 tgδ ≤ 0,0010.

Так же разница заметна и по другим номиналам (WIMA FKP2 хуже).
Сравнивал WIMA FKP2: 33 пФ, 47 пФ, 100 пФ, 220 пФ с керамическими зелеными КМ (33 пФ, 47 пФ, 100 пФ); с КВИ (47 пФ и 100 пФ); с 250 пФ (два последовательно соединенных полистирольных аксиальных импортных по 510 пФ).
Сравнивал WIMA FKP2: 1 nF с К78-2 1600 В; с советским аксиальным полистиролным 1000 пФ, на нем красным надпись "1000"; с 1500 пФ коричневым из распайки телевизора, размеры 13,5х10х6 мм.

LOAD калибровку начинаем с седьмого диапазона. Сначала вводим в меню прибора приблизительную емкость эталонного резистора для 7-го диапазона. После прохождения LOAD калибровки по эталонному резистору зажимаем в щупы конденсатор 0,5 пФ и смотрим его Rs на частоте 10 кГц.
Почему на 10 кГц, да потому что на более высокой частоте одна и та же емкость резистора больше двигает фазу, чем на более низкой частоте. И откалибровав диапазон приблизительно (грубо) на частоте 10 кГц, получим более точную калибровку фазы на 1 кГц и 100 Гц.
Rs конденсатора 0,5 пФ на 10 кГц должен находиться не в минусе и не в преобладающем плюсе, а будет колебаться (плавать) относительно нуля то в плюс то в минус, лучше с небольшим преобладанием в плюс. Rs, а также тангенс угла диэлектрических потерь не стабильны из-за действующих наводок частотой 50 Гц. Эти наводки особенно сильно заметны на 7-м диапазоне.
Наиболее вероятно, что с первого раза Вы не угадали емкость резистора (Cstd), и Rs конденсатора получился или в большом минусе или в большом плюсе. Тогда надо изменить значение емкости резистора в меню (Cstd) для данного диапазона и повторить LOAD калибровку. Скажу, что для 7-го диапазона емкость резистора придется подбирать до сотых долей, или даже до тысячных долей пФ. И важно при каждой повторной LOAD калибровке зажимать щупы в одинаковых положениях на выводах резистора. После получения требуемого результата взять конденсатор 10 пФ и измерить его тангенс на частоте 1 кГц (на седьмом откалиброванном диапазоне). Калибровка фазового угла 7-го диапазона на частоте 1 кГц получилась более точной, чем на частоте 10 кГц, поэтому измеренный тангенс конденсатора 10 пФ на 1 кГц получится близким реальному на этой частоте.
Далее делаем LOAD калибровку 6-го диапазона по приблизительно введенной емкости резистора. После калибровки измеряем Rs и тангенс конденсатора 10 пФ на 10 кГц (6-й диапазон). Rs должен быть положительным, а тангенс в четвертом знаке после запятой, вблизи 0,0005. Если не получилось, то изменяем емкость Cstd для 6-го диапазона и повторяем LOAD калибровку 6-го диапазона. По окончанию калибровки 6-го диапазона, измерьте тангенс высокодобротного конденсатора 100 пФ на частоте 1 кГц (6 диапазон). Тангенс будет близок к реальному на этой частоте.
Аналогично выполняем LOAD калибровку 5-го диапазона, проверяя калибровку по Rs и по тангенсу конденсатора 100 пФ на 10 кГц, на 5-м диапазоне. И проверяем тангенс конденсатора 1000 пФ на 1 кГц, на том же 5-м диапазоне.

Аналогично выполняем LOAD калибровку 4-го диапазона, проверяя калибровку по Rs и по тангенсу конденсатора 1000 пФ на 10 кГц, на 4-м диапазоне. И проверяем тангенс конденсатора 0,01 мкФ на 1 кГц, на том же 4-м диапазоне.
LOAD калибровка диапазонов 3, 2, 1, 0 получается достаточно точной без подбора реактивности резисторов. Я, например, калибрую эти диапазоны по проволочным резисторам мощностью 0,25 Вт, ввожу реактивность для 3-го диапазона 0 пФ, а для 2, 1, 0 диапазонов – 0,05 мкГн. Сдвиг Lstd даже в пределах десятых долей мкГн, или Cstd на единицы пФ, не оказывает заметного влияния на калибровку (на установку фазового угла) на этих диапазонах.
Если есть возможность измерить тангенс конденсаторов на профессиональном измерителе с четырьмя или больше знаками после запятой, то это лучший вариант, чтобы сравнить результаты измерения с RLC-2.
В качестве высокодобротного воздушного конденсатора, емкостью близко 0,5 пФ можно использовать разрядники с платы кинескопа ЭЛТ мониторов. Фото привожу здесь:

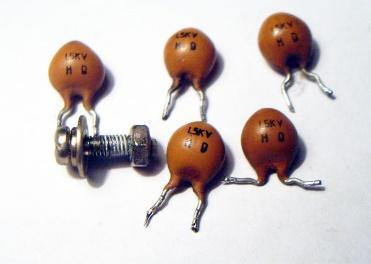
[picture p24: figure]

»

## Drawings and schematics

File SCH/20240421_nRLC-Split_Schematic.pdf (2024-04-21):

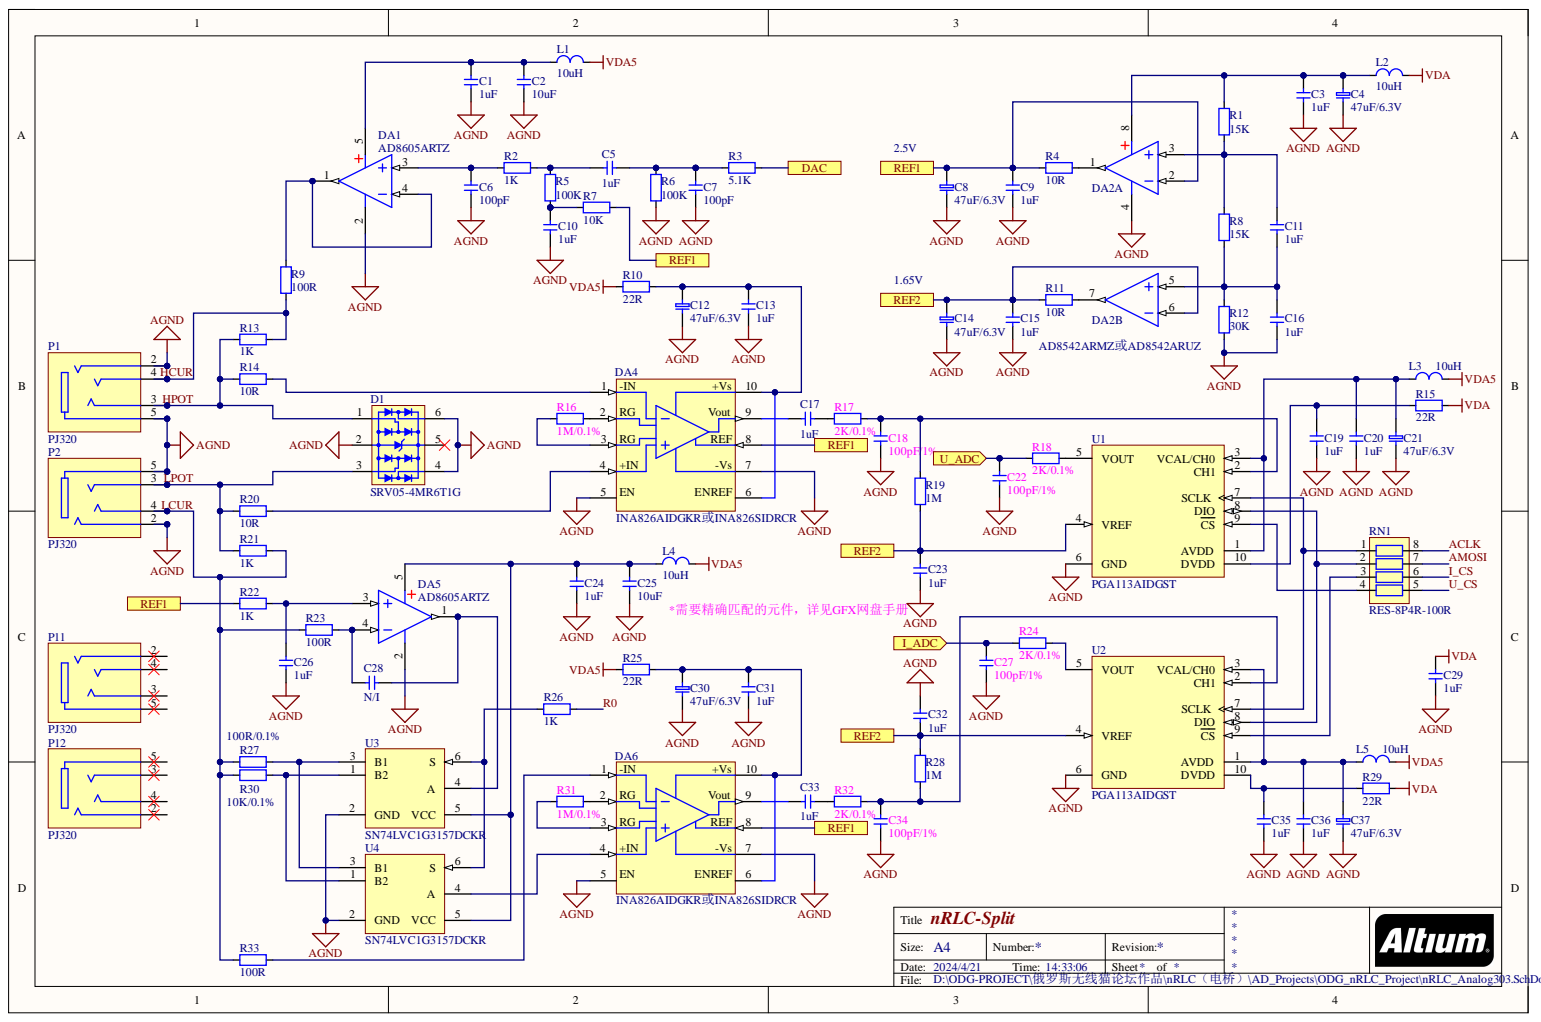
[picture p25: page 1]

D:\ODG-PROJECT\俄罗斯无线猫论坛作品\nRLC（电桥）\AD_Projects\ODG_nRLC_Project\nRLC_Analog303.SchDoc
File:

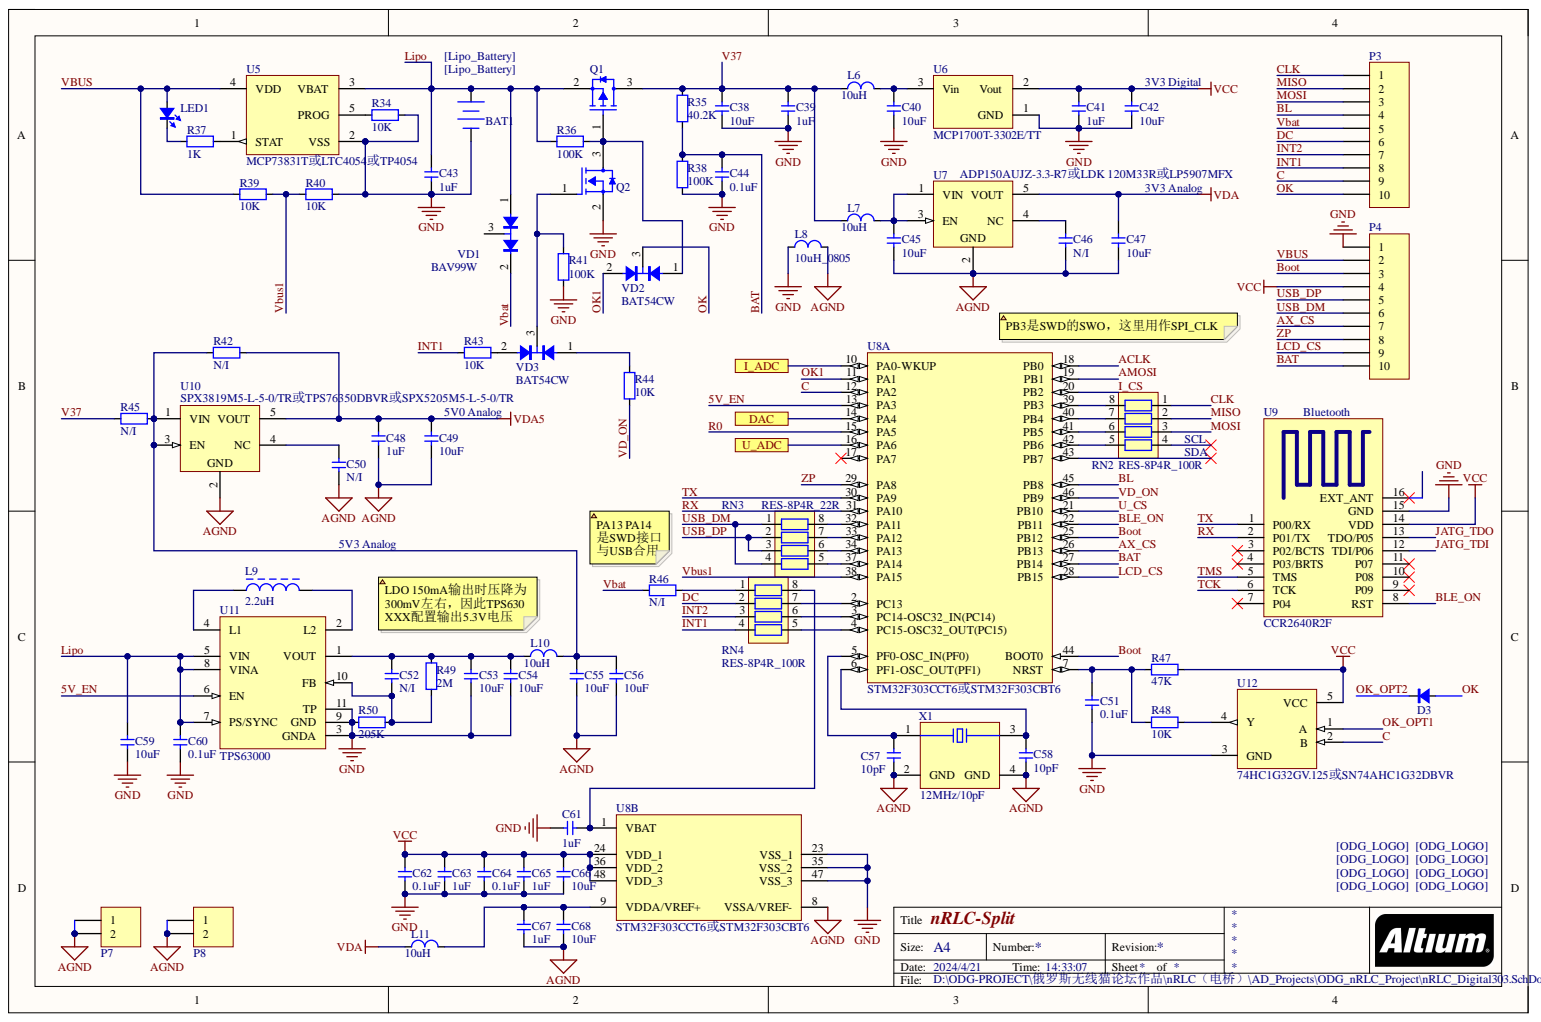
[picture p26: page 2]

3 | | 6 | PA13 34
4 | 5 | PA14 37 | | P03/BRTS 4

PA15 38 | | TMS 5 TCK 6

D:\ODG-PROJECT\俄罗斯无线猫论坛作品\nRLC（电桥）\AD_Projects\ODG_nRLC_Project\nRLC_Digital303.SchDoc
File:

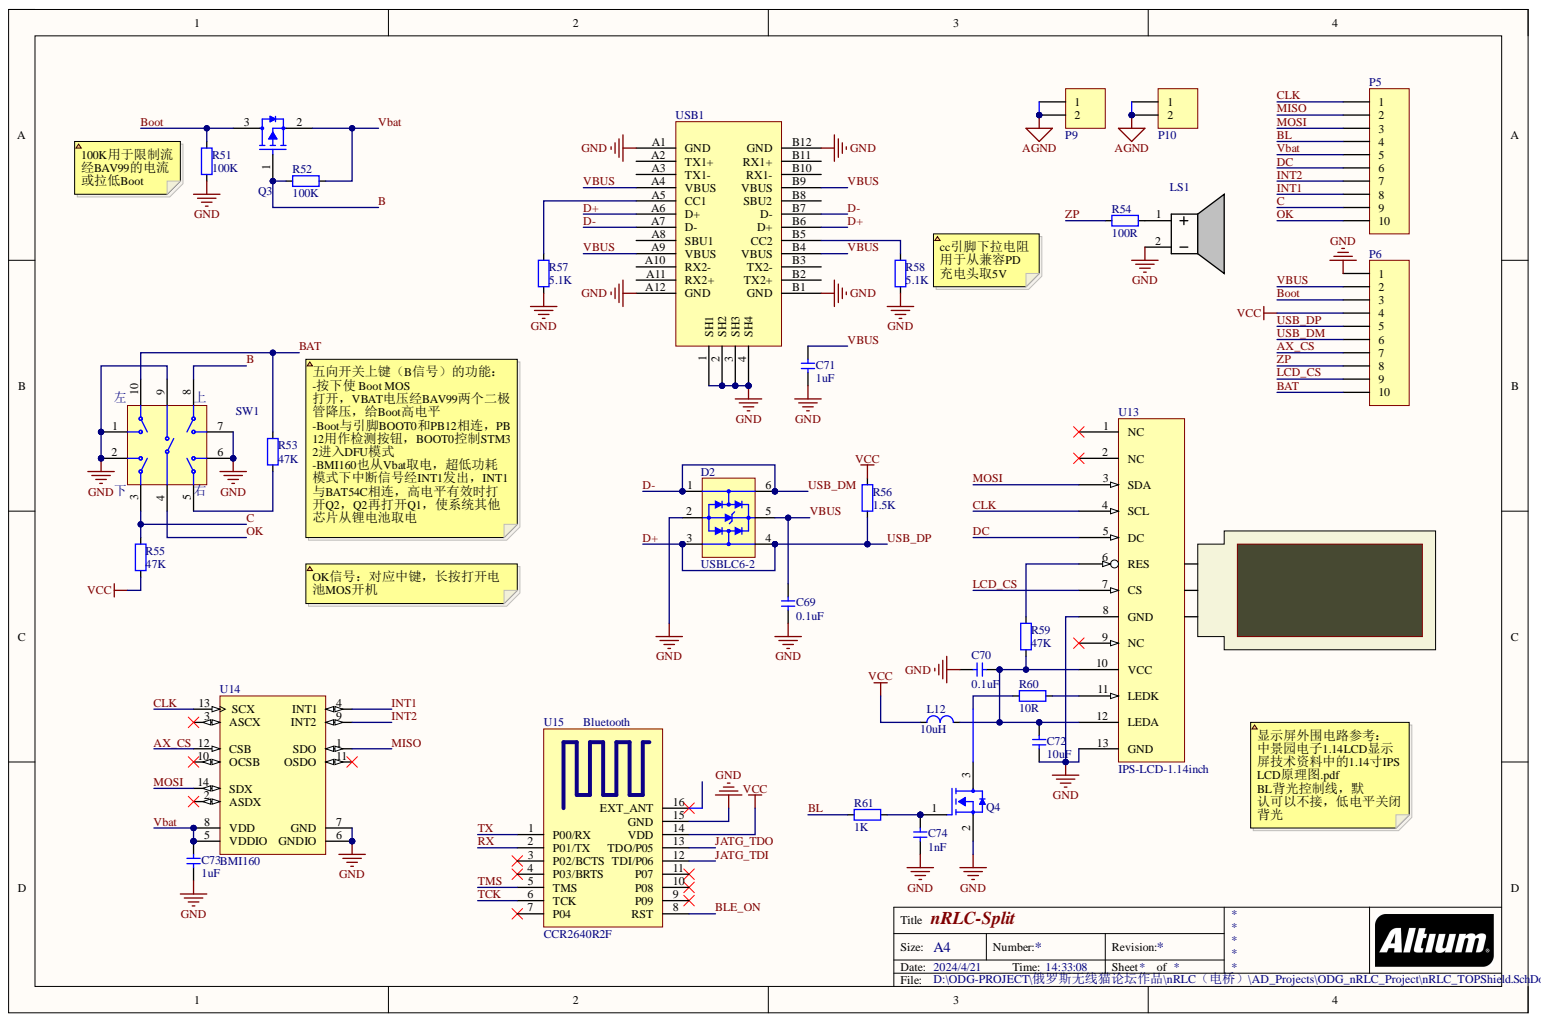
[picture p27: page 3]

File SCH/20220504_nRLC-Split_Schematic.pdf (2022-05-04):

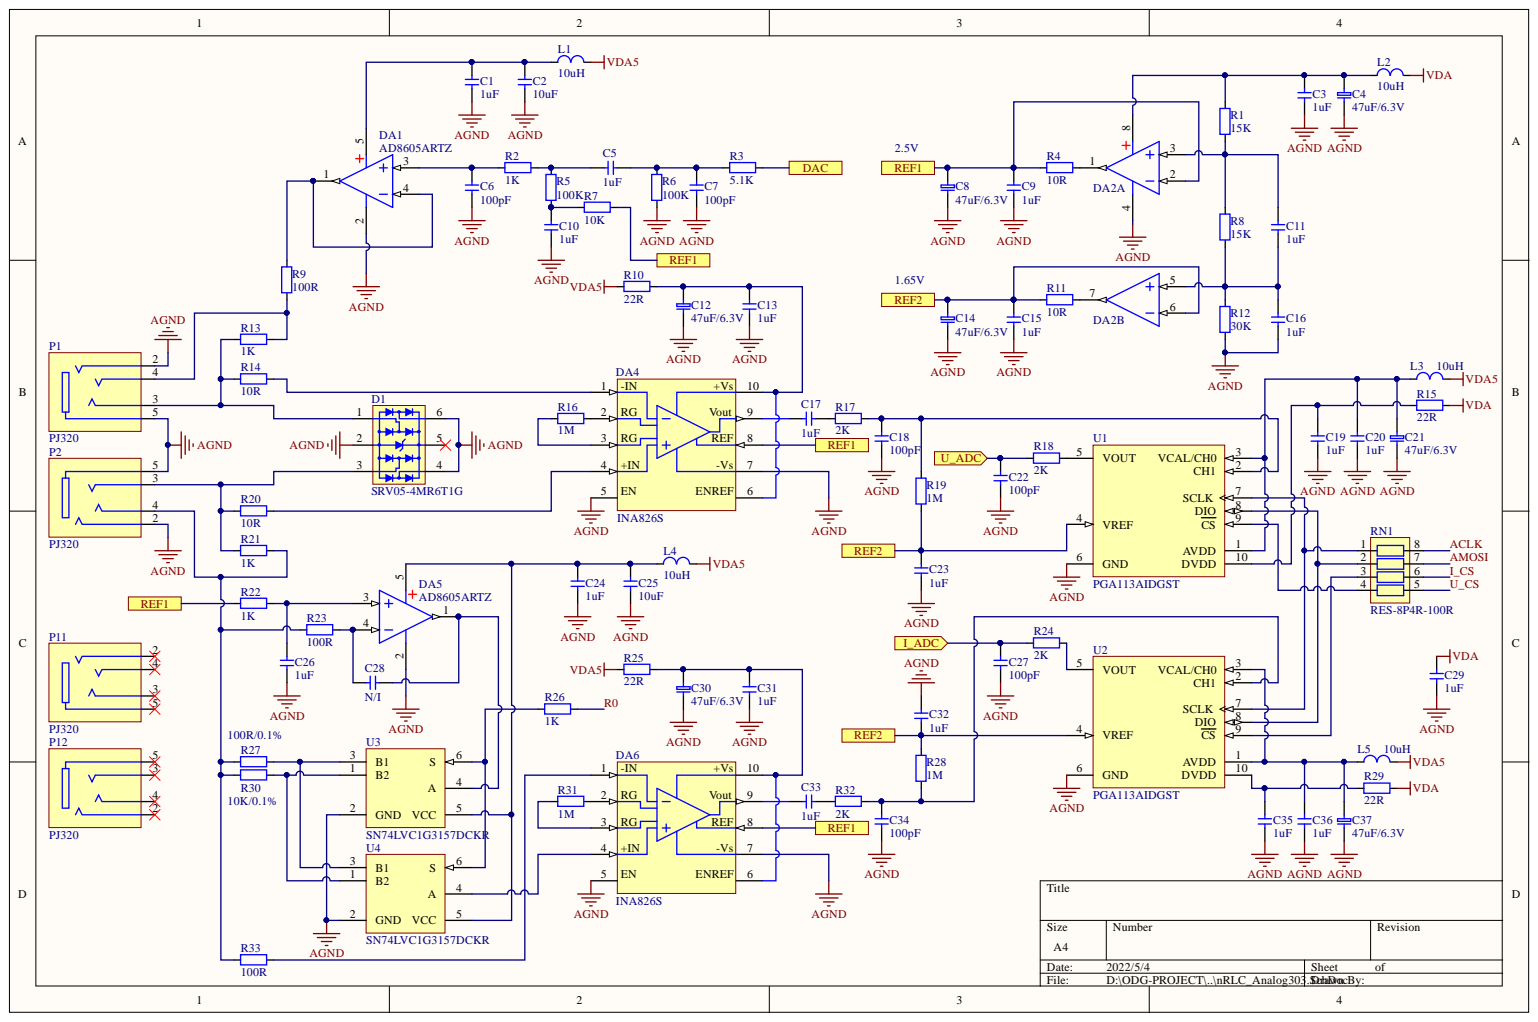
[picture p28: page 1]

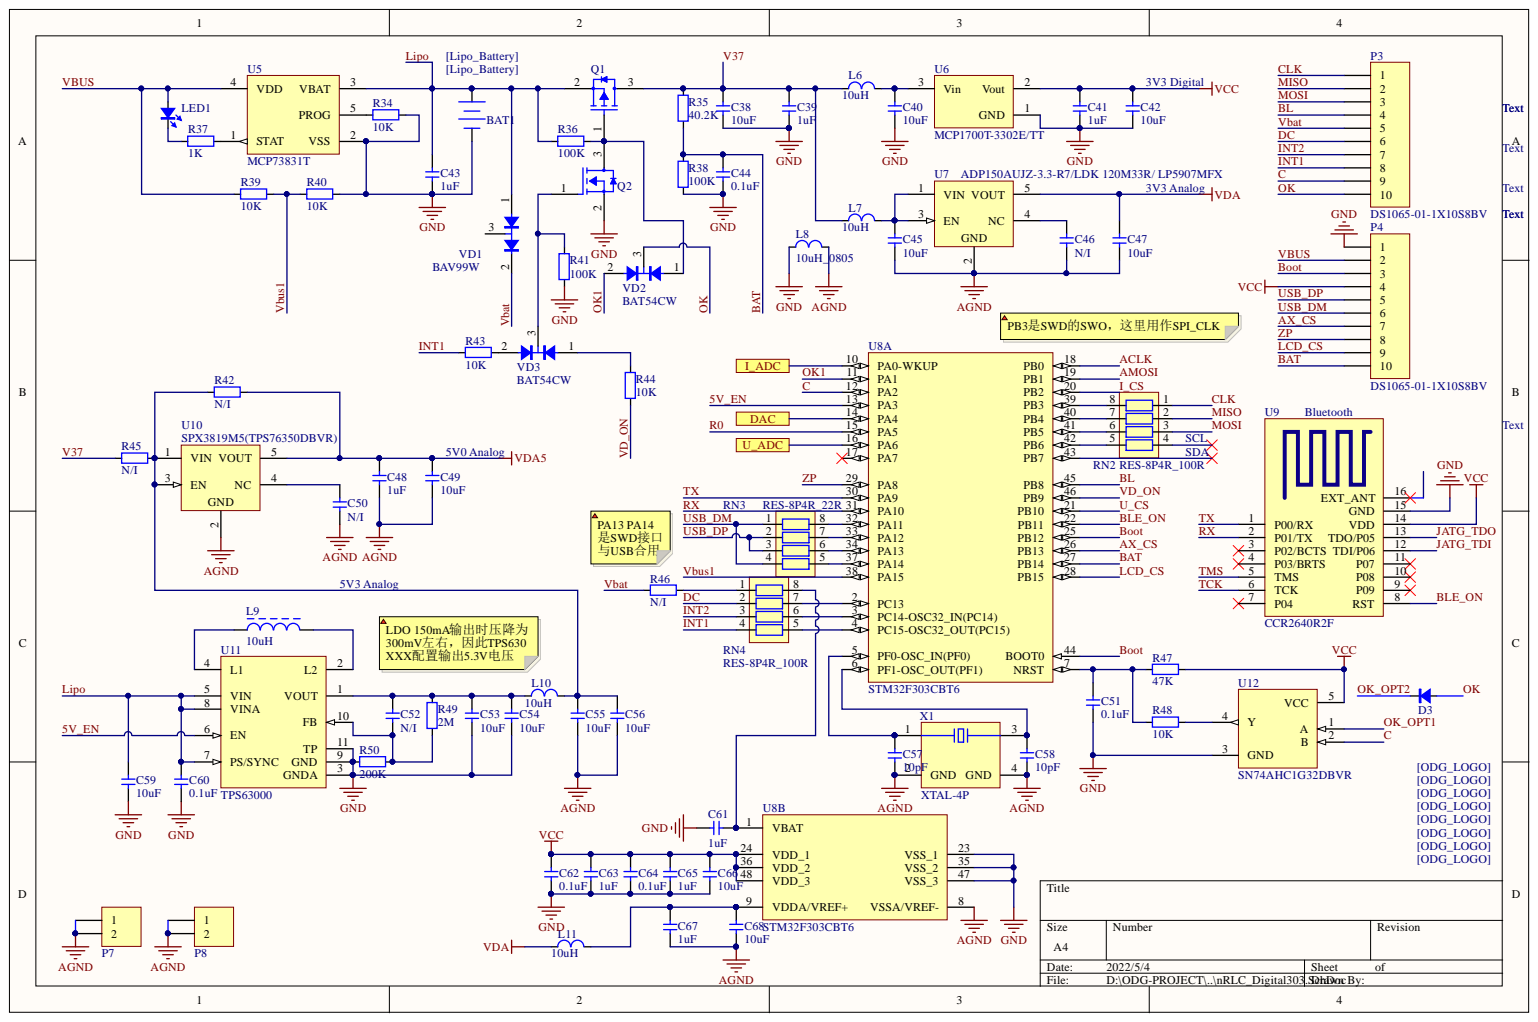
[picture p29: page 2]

PA4 14
PA5 15 | 6 | 3 | P00/RX 1 P01/TX 2 P02/BCTS 3
PA6 16 | 5 | 4 SCL

3 | | 6 | PA13 34
4 | 5 | PA14 37 | | P03/BRTS 4

PA15 38 | | TMS 5 TCK 6

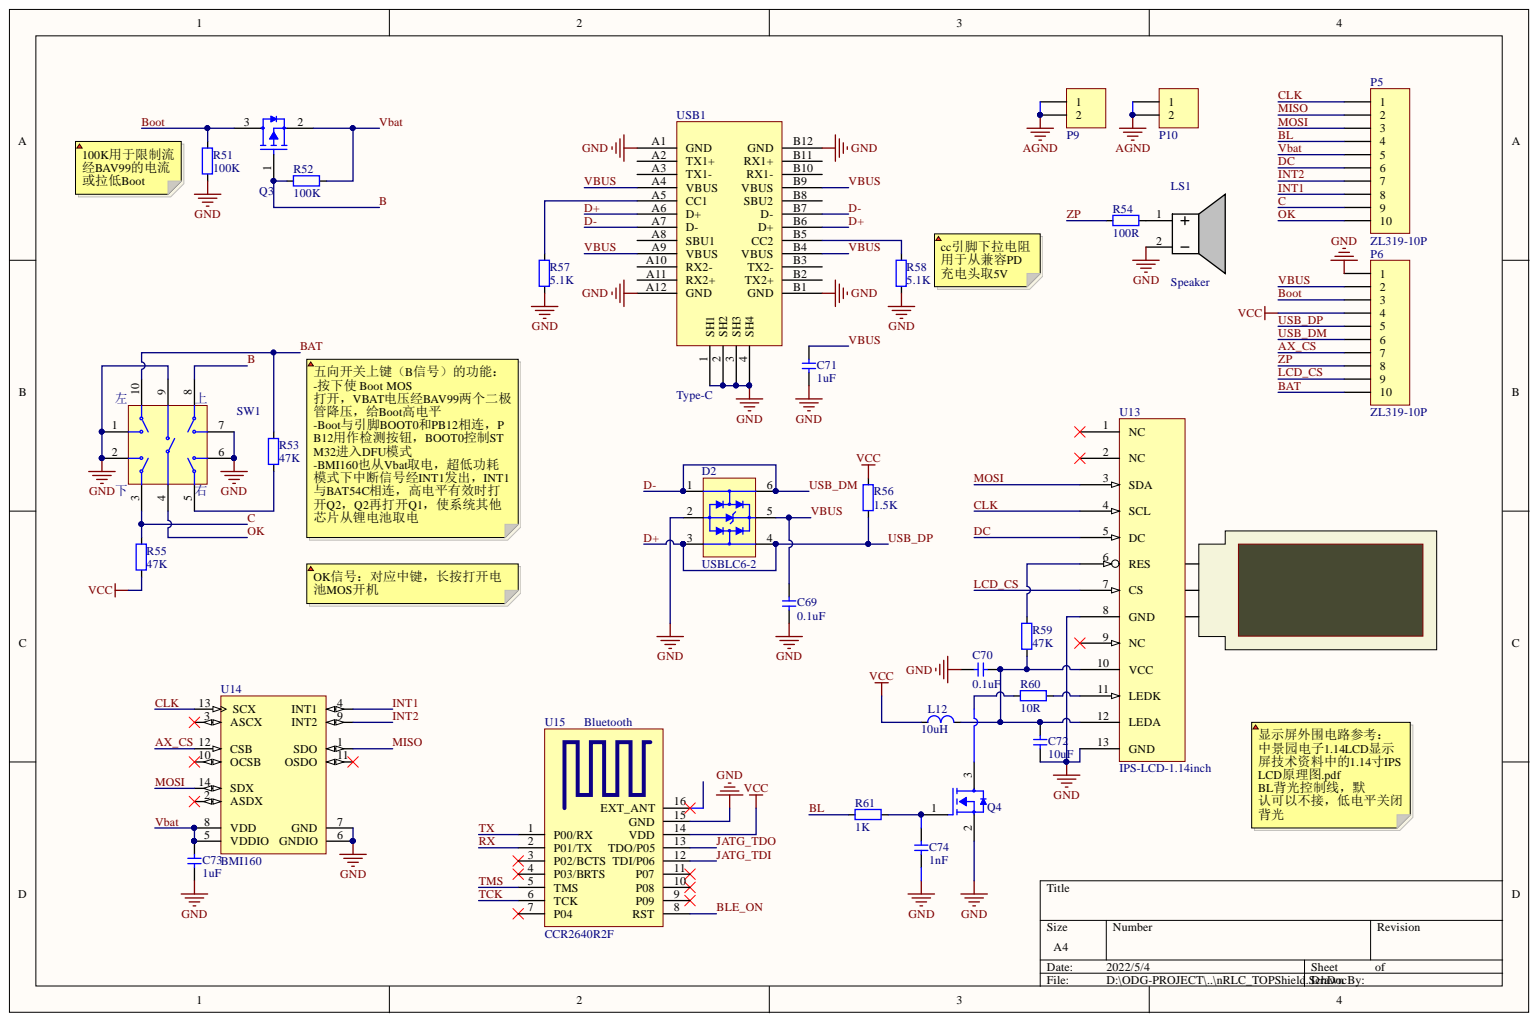
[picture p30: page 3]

K信号：对应中键，长按打开电 池MOS开机

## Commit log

2022-03-20 1st commit
    [BOM.csv, Pick Place for nRLC_Project.csv, Tweezers_tips.DWG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]
2022-03-20 修改readme
2022-03-20 修改 README
2022-03-20 添加外壳五金件说明
2022-03-21 R50从200K修改为205K
2022-03-21 添加整机收纳外壳
    [整机收纳壳(machine storage case).STL]
2022-03-23 补充BOM没说清楚的地方
    [镊子外壳-下壳(tweezers_case_bottom).STL]
2022-03-23 补充BOM描述
2022-03-24 修改了镊子Gerber文件
2022-03-25 修正BOM锂电池尺寸为402025
2022-03-25 添加镊子接触头的README.md
2022-03-26 添加README.md的叠层顺序说明
2022-05-04 R44修改为10K，之前100K是错误的，感谢@BLACK发现问题
